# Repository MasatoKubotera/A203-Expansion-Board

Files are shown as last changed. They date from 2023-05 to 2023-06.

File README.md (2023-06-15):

<html lang="en">

<head>
    <meta charset="uft-8">
    <meta name="author" content="Masato Kubotera">
    <meta name="description" content="">
</head>

<body>
    <p><strong>This product is currently under development!</strong></p>
    <h1>A203 V2 Expansion Board</h1>
        <p>
            This product is a board that expands the functions of the A203 (Version 2) carrier board manufactured by Seeed Stuido, developed for the SUSTAINA-OP<sup>TM</sup>. Several modules developed for SUSTAINA-OP<sup>TM</sup> can be attached/connected to this board and used by connecting to the Multifunctional Port and USB Port on the carrier board. In addition, the USB 2.0 High Speed(480MHz) 3-Port Hub is installed for further expandability.
        </p>
    <h2>Features Rev. 1</h2>
        <p>
            <table>
                <tr>
                    <th>Top Surface of PCB</th>
                    <th>Bottom Surface of PCB</th>
                    <th>Assembled Electronic Components</th>
                </tr>
                <tr>
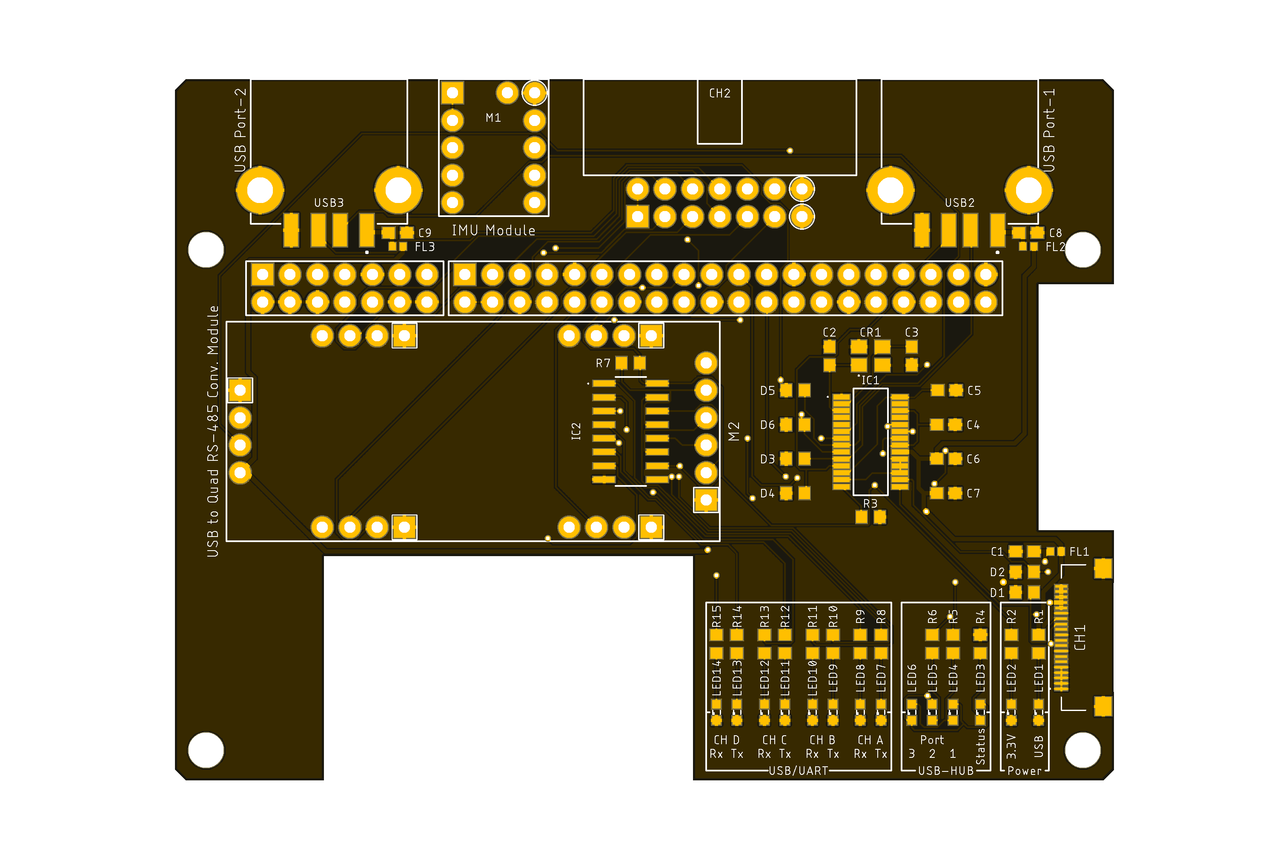
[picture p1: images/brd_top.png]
                    <td></td>
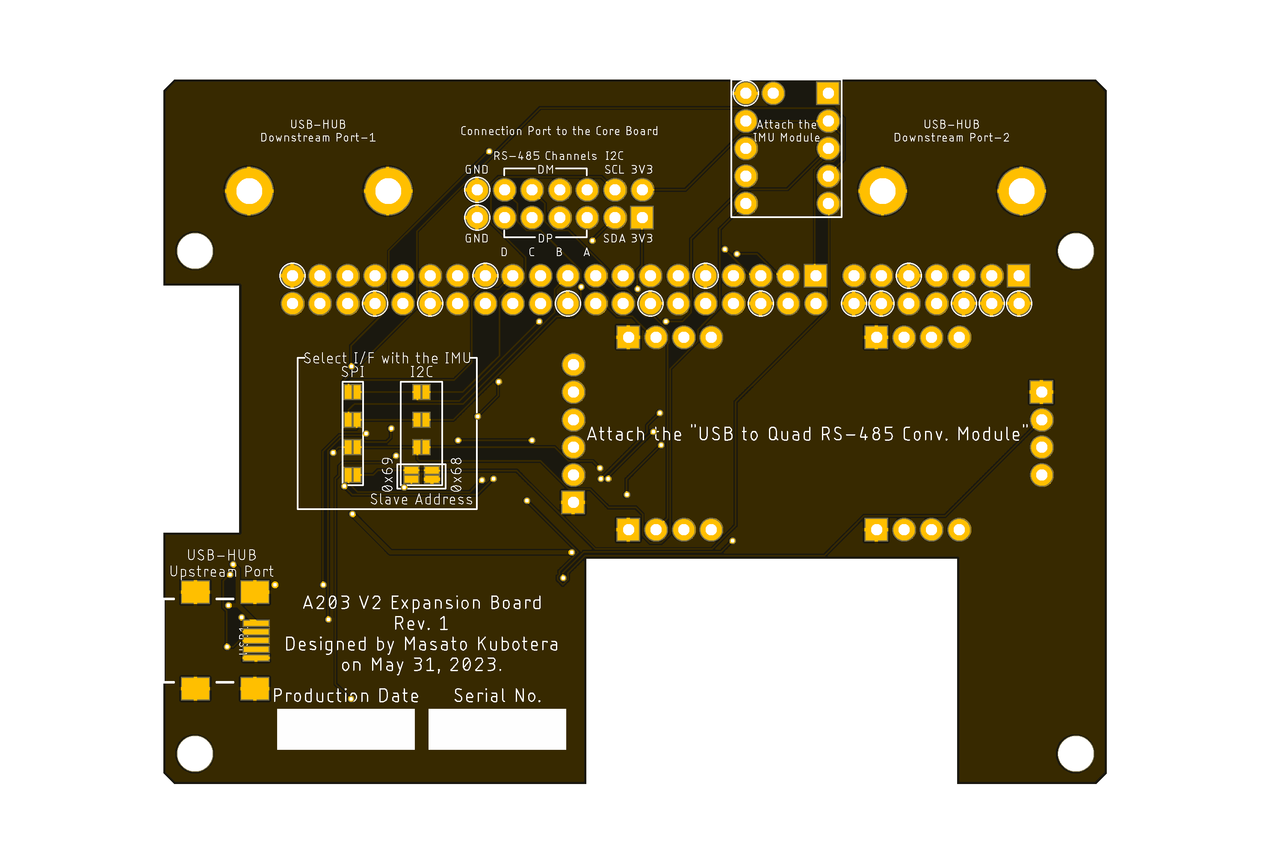
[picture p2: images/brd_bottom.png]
                    <td></td>
                    <td></td>
                </tr>
            </table>
        </p>
    <h3>PCB</h3>
        <p>
            <ul>
                <li>81.20mm x 46.40mm PCB layout</li>
                The shape of the connector does not interfere with the connectors on the A203 V2.
                <li>Two types of USB-HUB Upstream Ports</li>
                    <ul>
                        <li>0.5mm pitch 20P ZIF Connector</li>
                        Compliant with W11: 20PIN(USB 3.0 ZIF) on the A203 V2.
                        <li>USB Mini-B Connector (Optional)</li>
                    </ul>
                <li>2 x USB 2.0 Type-A USB-HUB Downstream Ports</li>
                <li>1 x <a href="https://github.com/SUSTAINA-OP/ICM-42688-P-Module">SUSTAINA-OP/ICM-42688-P-Module</a> Attachment Port</li>
                The I/F with A203V2 can be selected from the following using the shortlands on the product.
                <ul>
                    <li>SPI </li>
                    <li>I2C: Selectable slave address 0x68/0x69</li>
                </ul>
                <li>1 x <a href="https://github.com/SUSTAINA-OP/USB-to-Quad-RS-485-Conv-Module">SUSTAINA-OP/USB-to-Quad-RS-485-Conv-Module</a> Attachment Port</li>
                <li>14 x LED Indicators</li>
                <li>
                    1 x Port for Connection to <a href="https://github.com/SUSTAINA-OP/SUSTAINA-Core-Board">SUSTAINA-OP/SUSTAINA-Core-Board</a>
                    <ul>
                        <li>2 x 7 Pin Flat Cable Connector (MIL Standard Connector)
                            <ul>
                                <li><strong>2 x 3V3</strong>: 3.3 V Power Supply</li>
                                <li><strong>SCL</strong>: I2C Serial Clock</li>
                                <li><strong>SDA</strong>: I2C Serial Data</li>
                                <li><strong>A-DP</strong>: RS-485 Data Signal Plus of CH-A</li>
                                <li><strong>A-DM</strong>: RS-485 Data Signal Minus of CH-A</li>
                                <li><strong>B-DP</strong>: RS-485 Data Signal Plus of CH-B</li>
                                <li><strong>B-DM</strong>: RS-485 Data Signal Minus of CH-B</li>
                                <li><strong>C-DP</strong>: RS-485 Data Signal Plus of CH-C</li>
                                <li><strong>C-DM</strong>: RS-485 Data Signal Minus of CH-C</li>
                                <li><strong>D-DP</strong>: RS-485 Data Signal Plus of CH-D</li>
                                <li><strong>D-DM</strong>: RS-485 Data Signal Minus of CH-D</li>
                                <li><strong>2 x GND</strong>: Common Ground</li>
                            </ul>
                        </li>
                    </ul>
                </li>
            </ul>
        </p>
    <h2>Development Environments</h2>
    <p>
        This product is designed with the following software.
            <ul>
                <li><a href="https://www.autodesk.com/products/eagle/overview">Autodesk Eagle 9.6.2</a></li>
            </ul>
    </p>
    <h2>Repository Contents</h2>
        <p>
            <dl>
                <dt><a href="/images">\images</a></dt>
                <dd>PCB preview images and capture of design screen</dd>
                <dt><a href="/libraries">\libraries</a></dt>
                <dd>Libraries used in Autodesk Eagle design</dd>
                <dt><a href="/pcb_order">\pcb_order</a> </dt>
                <dd>Gerber data and documentation for ordering PCB</dd>
                <dt><a href="/schematic.pdf">schematic.pdf</a></dt>
                <dd>Circuit diagram of this product</dd>
                <dt>*.brd</dt>
                <dd>Board wiring design file by Autodesk Eagle</dd>
                <dt>*.sch</dt>
                <dd>Circuit diagram design file by Autodesk Eagle</dd>
                <dt><a href="/.gitignore">.gitignore</a></dt>
                <dd>A file that tells Git not to track a particular file</dd>            <dt><a href="/LICENSE">LICENSE</a></dt>
                <dd>License to use this product</dd>
            </dl>
        </p>
    <h2>Documentation</h2>
        <p>
            The following documents are available for this product.
            <ul>
                <li><a href="/pcb_order/README.md">\pcb_order\README.md</a>: Information for ordering the PCB or PCBA</li>
            </ul>
        </p>
    <h2>References</h2>
        
    <h2>Contact</h2>
        <p>
            If you have any questions, please contact the designer of this product, Masato Kubodera, by <a href="mailto:masato.kubotera@sustaina-op.com">e-mail</a>.<br>
            E-mail: <a href="mailto:masato.kubotera@sustaina-op.com">masato.kubotera@sustaina-op.com</a>
        </p>
    <h2>License Information</h2>
        <p>
            This product is open source. Please review the <a href="/LICENSE">LICENSE</a> for license information.<br>
            <br>
            This product by Masato Kubotera is licensed under a <a href="http://creativecommons.org/licenses/by-nc-sa/4.0/">Creative Commons Attribution-NonCommercial-ShareAlike 4.0 International License</a>.
        </p>
</body>
</html>

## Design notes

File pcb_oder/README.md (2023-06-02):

<html lang="en">

<head>
	<meta charset="uft-8">
	<meta name="author" content="Masato Kubotera">
    <meta name="description" content="">
</head>

<body>
	<h1>PCB / PCBA Order</h1>
        <p>
            PCB/PCBA ordering were outsourced to <a href="https://jlcpcb.com/">JLCPCB</a>.<br>
            The following files were used to generate files for PCB/PCBA orders.
            <ul>
                <li>Eagle Design File:
                    <a href="https://github.com/JLCPCB/jlcpcb-eagle/blob/master/design%20rules/jlcpcb-2layers.dru">jlcpcb-2layers.dru</a>
                </li>
                <li>Eagle CAM File:
                    <a href="https://github.com/JLCPCB/jlcpcb-eagle/blob/master/cam/jlcpcb_2_layer_v9.cam">jlcpcb_2_layer_v9.cam</a>
                </li>
                <li>BOM/CPL Exporter ULPs:
                    <a href="https://github.com/JLCPCB/jlcpcb-eagle/blob/master/ulps/jlcpcb_smta_exporter.ulp">jlcpcb_smta_exporter.ulp</a>
                </li>
            </ul>
            These are distributed in <a href="https://github.com/JLCPCB/jlcpcb-eagle">github.com/JLCPCB/jlcpcb-eagle</a>.<br>
        </p>
    <h2>PCB Order Specifications</h2>
        <p>           
            <table>
                <tr>
                    <th>PCB Top Image</th>
                    <th>PCB Bottom Image</th>
                </tr>
                <tr>
                    <td></td>
                    <td></td>
                </tr>
            </table>
            The following  files used to order the PCB and their specifications. 
            <ul>
                <li>Gerber data: <a href="Gerber_date.zip">Gerber_date.zip</a></li>
            </ul>
            <details close>
                <summary>Click for more specifications</summary>
                <ul>                
                    <li>Base Material: FR-4</li>
                    <li>Layers: 2</li>
                    <li>Dimension: 87 mm* 65 mm</li>
                    <li>Product Type: Industrial/Consumer electronics</li>
                    <li>Different Design: 1</li>
                    <li>Delivery Format: Single PCB</li>
                    <li>PCB Thickness: 1.6</li>
                    <li>Impedance Control: no</li>
                    <li>PCB Color: Black</li>
                    <li>Silkscreen: White</li>
                    <li>Surface Finish: HASL(with lead)</li>
                    <li>Outer Copper Weight: 1 oz</li>
                    <li>Via Covering: Tented</li>
                    <li>Board Outline Tolerance: ±0.2mm(Regular)</li>
                    <li>Confirm Production file: No</li>                
                    <li>Remove Order Number: Yes</li>
                    <li>Deburring/Edge rounding: No</li>
                    <li>Flying Probe Test: Fully Test</li>
                    <li>Gold Fingers: No</li>
                    <li>Castellated Holes: No</li>
                    <li>4-Wire Kelvin Test: No</li>
                    <li>Paper between PCBs: No</li>
                    <li>Appearance Quality: IPC Class 2 Standard</li>
                    <li>Silkscreen Technology: Ink-jet/Screen Printing</li>
                    <li>Package Box: With JLCPCB logo</li>
                </ul>
            </details>
        </p>
    <h2>PCBA Order Specifications</h2>
        <p>
            <table>
                <tr><th>PCBA Image</th></tr>
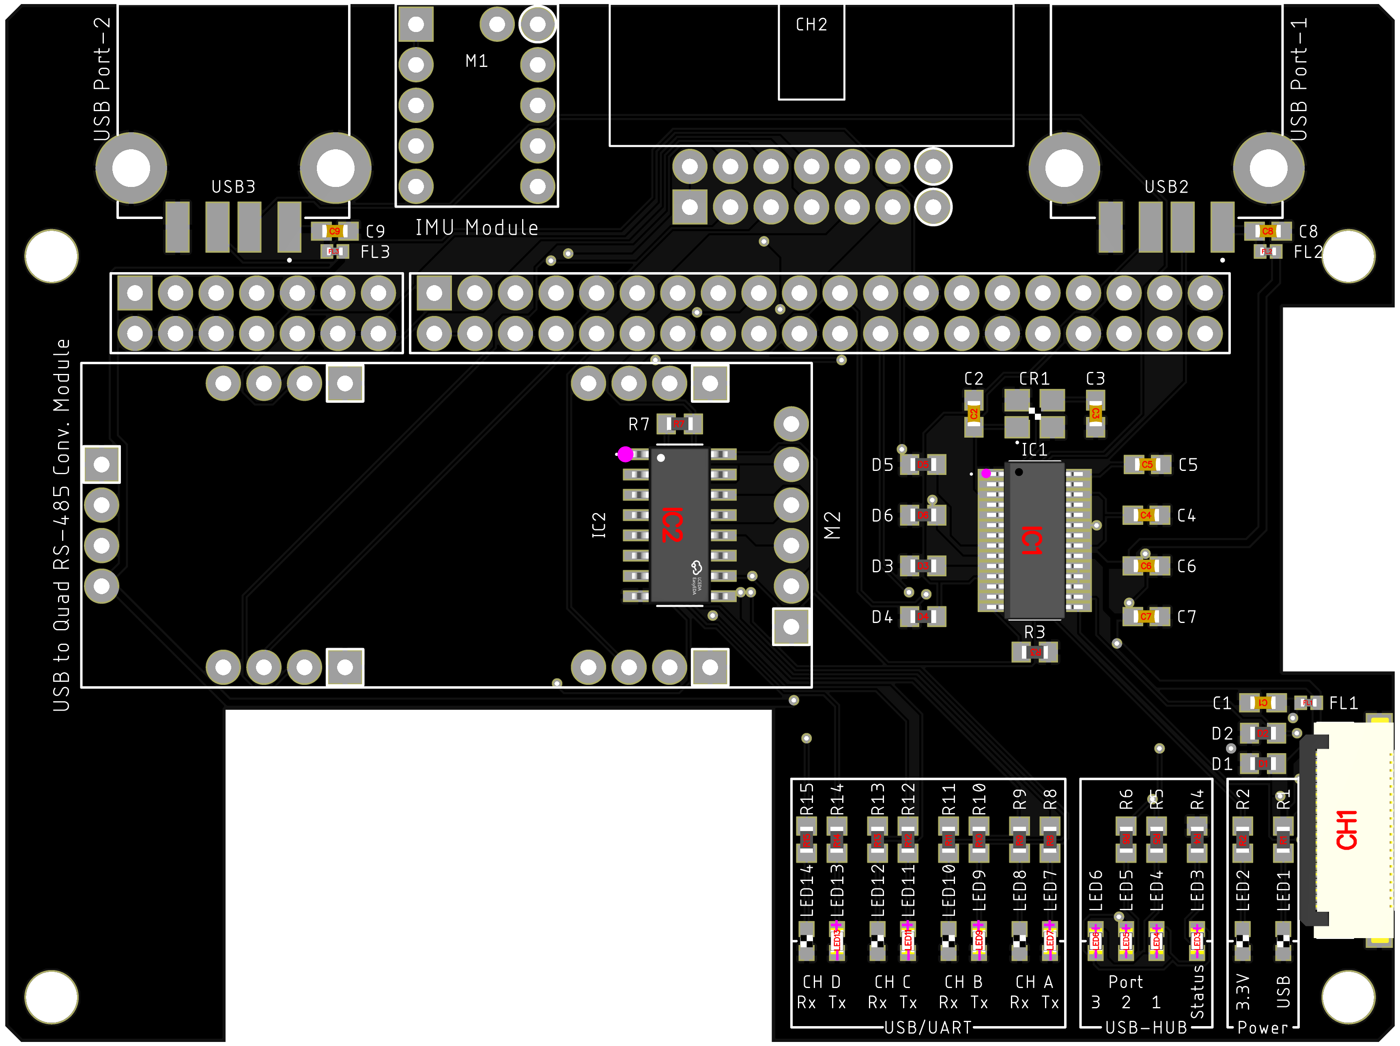
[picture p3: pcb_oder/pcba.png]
                <tr><td></td></tr>
            </table>
            The following files used to order the PCBA and their specifications.
            <ul>
                <li>BOM File: <a href="A203-V2-Expansion-Board_top_bom.csv">A203-V2-Expansion-Board_top_bom.csv</a></li>
                <li>CPL File: <a href="A203-V2-Expansion-Board_top_cpl.csv">A203-V2-Expansion-Board_top_cpl.csv</a></li>
            </ul>
            The following components were installed by PCBA.
            <table>
                <tr>
                    <th>Part Image</th>
                    <th>Top Designator</th>
                    <th>MFR.Part #</th>
                    <th>JLCPCB Part #</th>
                    <th>Manufacturer</th>
                    <th>Part Detail</th>
                </tr>
                <tr>
                    <td></td>
                    <td>C1, C7, C8, C9</td>
                    <td>GCM188R71H103KA37D</td>
                    <td><a href="https://jlcpcb.com/partdetail/MurataElectronics-GCM188R71H103KA37D/C85863">C85863</a></td>
                    <td>Murata Electronics</td>
                    <td>Multilayer Ceramic Capacitor SMD 10nF 50V ±10% X7R 0603</td>
                </tr>
                <tr>
                    <td></td>
                    <td>C2, C3</td>
                    <td>C1608C0G1H220JT000N</td>
                    <td><a href="https://jlcpcb.com/partdetail/Tdk-C1608C0G1H220JT000N/C183114">C183114</a></td>
                    <td>TDK</td>
                    <td>Multilayer Ceramic Capacitor SMD 22pF 50V ±5% C0G 0603</td>
                </tr>
                <tr>
                    <td></td>
                    <td>C4, C5, C6</td>
                    <td>GRM188R61C106KAALD</td>
                    <td><a href="https://jlcpcb.com/partdetail/MurataElectronics-GRM188R61C106KAALD/C86275">C86275</a></td>
                    <td>Murata Electronics</td>
                    <td>Multilayer Ceramic Capacitor SMD 10uF 16V ±10% X5R 0603</td>
                </tr>
                <tr>
                    <td></td>
                    <td>CR1</td>
                    <td>7V12006001</td>
                    <td><a href="https://jlcpcb.com/partdetail/TxcCorp-7V12006001/C5203634">C5203634</a></td>
                    <td>TXC Corp</td>
                    <td>Crystal 12Hz ±30ppm 12pF SMD 3225-4P</td>
                </tr>
                <tr>
                    <td></td>
                    <td>CH1</td>
                    <td>XF2M-2015-1A</td>
                    <td><a href="https://jlcpcb.com/partdetail/OmronElectronics-XF2M_20151A/C57541">C57541</a></td>
                    <td>Omron Electronics</td>
                    <td>FFC/FPC Connector SMD　20-pin 0.5mm Pitch Double-sided</td>
                </tr>
                <tr>
                    <td></td>
                    <td>D1, D2, D3, D4, D5, D6</td>
                    <td>PGB1010603MR</td>
                    <td><a href="https://jlcpcb.com/partdetail/Littelfuse-PGB1010603MR/C142698">C142698</a></td>
                    <td>Littelfuse</td>
                    <td>ESD Suppressor SMD 24V 0.06pF 0603</td>
                </tr>
                <tr>
                    <td></td>
                    <td>FL1,FL2,FL3</td>
                    <td>BLM15AX601SN1D</td>
                    <td><a href="https://jlcpcb.com/partdetail/MurataElectronics-BLM15AX601SN1D/C76886">C76886</a></td>
                    <td>Murata Electronics</td>
                    <td>Ferrite Bead SMD 600Ω ±25% 500mA 0402</td>
                </tr>
                <tr>
                    <td></td>
                    <td>IC1</td>
                    <td>FE1.1S</td>
                    <td><a href="https://jlcpcb.com/partdetail/TerminusTech-FE1_1SBSOP28BCN/C9359">C9359</a></td>
                    <td>Terminus Tech</td>
                    <td>USB Interface IC USB 2.0 Hi-Speed 4-port Hub Controller SSOP-28</td>
                </tr>
                <tr>
                    <td></td>
                    <td>IC2</td>
                    <td>SN74HC595DR</td>
                    <td><a href="https://jlcpcb.com/partdetail/TexasInstruments-SN74HC595DR/C10092">C10092</a></td>
                    <td>Texas Instruments</td>
                    <td>Shift Register 8-bit 6V SOIC-16</td>
                </tr>
                <tr>
                    <td></td>
                    <td>LED1, LED2, LED8, LED10, LED12, LED14</td>
                    <td>SML-D12M1WT86</td>
                    <td><a href="https://jlcpcb.com/partdetail/RohmSemicon-SMLD12M1WT86/C2922668">C2922668</a></td>
                    <td>ROHM Semicon</td>
                    <td>Standard LED SMD GREEN 2.2V 20mA 572nm 0603
                </tr>
                <tr>
                    <td></td>
                    <td>LED3, LED4, LED5, LED6</td>
                    <td>SML-D12Y1WT86</td>
                    <td><a href="https://jlcpcb.com/partdetail/RohmSemicon-SMLD12Y1WT86/C253534">C253534</a></td>
                    <td>ROHM Semicon</td>
                    <td>Standard LED SMD YELLOW 2.2V 20mA 590nm 0603</td>
                </tr>             
                <tr>
                    <td></td>
                    <td>LED7, LED9, LED11, LED13</td>
                    <td>SML-D12V1WT86</td>
                    <td><a href="https://jlcpcb.com/partdetail/RohmSemicon-SMLD12V1WT86/C253533">C253533</a></td>
                    <td>ROHM Semicon</td>
                    <td>Standard LED SMD RED 2.2V 20mA 630nm 0603</td>
                </tr>
                <tr>
                    <td></td>
                    <td>R1, R2, R4, R5, R6, R8, R9, R10, R11, R12, R13, R14, R15</td>
                    <td>RC0603FR-071KL</td>
                    <td><a href="https://jlcpcb.com/partdetail/Yageo-RC0603FR071KL/C22548">C22548</a></td>
                    <td>YAGEO</td>
                    <td>Thick Film Resistor SMD 1kΩ 1/10W ±1% 0603</td>
                </tr>
                <tr>
                    <td></td>
                    <td>R3</td>
                    <td>RC0603FR-072K7L</td>
                    <td><a href="https://jlcpcb.com/partdetail/Yageo-RC0603FR072K7L/C114612">C114612</a></td>
                    <td>YAGEO</td>
                    <td>Thick Film Resistor SMD 2.7kΩ 1/10W ±1% 0603</td>
                </tr>
                <tr>
                    <td></td>
                    <td>R7</td>
                    <td>RC0603FR-0710KL</td>
                    <td><a href="https://jlcpcb.com/partdetail/Yageo-RC0603FR0710KL/C98220">C98220</a></td>
                    <td>YAGEO</td>
                    <td>Thick Film Resistor SMD 10kΩ 1/10W ±1% 0603</td>
                </tr>
            </table>
            The following components are not handled by JLCPCB and could not be attached by PCBA.
            <table>
                <tr>
                    <th>Top Designator</th>
                    <th>MFR.Part #</th>
                    <th>Distributor / Part #</th>
                    <th>Manufacturer</th>
                    <th>Part Detail</th>
                </tr>
                <tr>
                    <td>CH2</td>
                    <td>HIF3FC-14PA-2.54DS(71)</td>
                    <td><a href="https://www.mouser.jp/ProductDetail/798-HIF3FC14PA254DS1">Mouser / 798-HIF3FC14PA254DS1</a></td>
                    <td><a href="https://www.hirose.com/en/product/p/CL0616-0062-2-71">Hirose Connector</a></td>
                    <td>Low Profile Connector 2.54mm-pitch 14-pin</td>
                </tr>
                <tr>
                    <td>USB2, USB3</td>
                    <td>USB1046-GF-0190-L-B-A</td>
                    <td><a href="https://www.mouser.jp/ProductDetail/640-USB1046GF0190LBA">Mouser / 640-USB1046GF0190LBA</a></td>
                    <td>GCT</td>
                    <td>USB Connectors SMD USB2.0 Type-A Top Mount</td>
                </tr>            
            </table>
            The following components were not attached due to being optional components to be attached to the bottom surface.
            <table>
                <tr>
                    <th>Top Designator</th>
                    <th>MFR.Part #</th>
                    <th>Distributor / Part #</th>
                    <th>Manufacturer</th>
                    <th>Part Detail</th>
                </tr>
                <tr>
                    <td>USB1</td>
                    <td>MUSB-5B-NE-S175</td>
                    <td><a href="https://akizukidenshi.com/catalog/g/gC-05843/">Akizuki / C-05843</a></td>
                    <td>Useconn Electronics Ltd.</td>
                    <td>USB Connectors SMD USB2.0 Mini-B Top Mount</td>
                </tr>           
            </table>
            These selected parts are listed in <a href="bom.xls">bom.xls</a>.<br>
            <details close>
                <summary>Click for more specifications</summary>
                <ul>                
                    <li>PCBA Type: Economic</li>
                    <li>Assembly Side: Top Side</li>
                    <li>Tooling holes: Added by JLCPCB</li>
                    <li>Confirm Parts Placement: No</li>
                </ul>
            </details>
        </p>
</body>

</html>

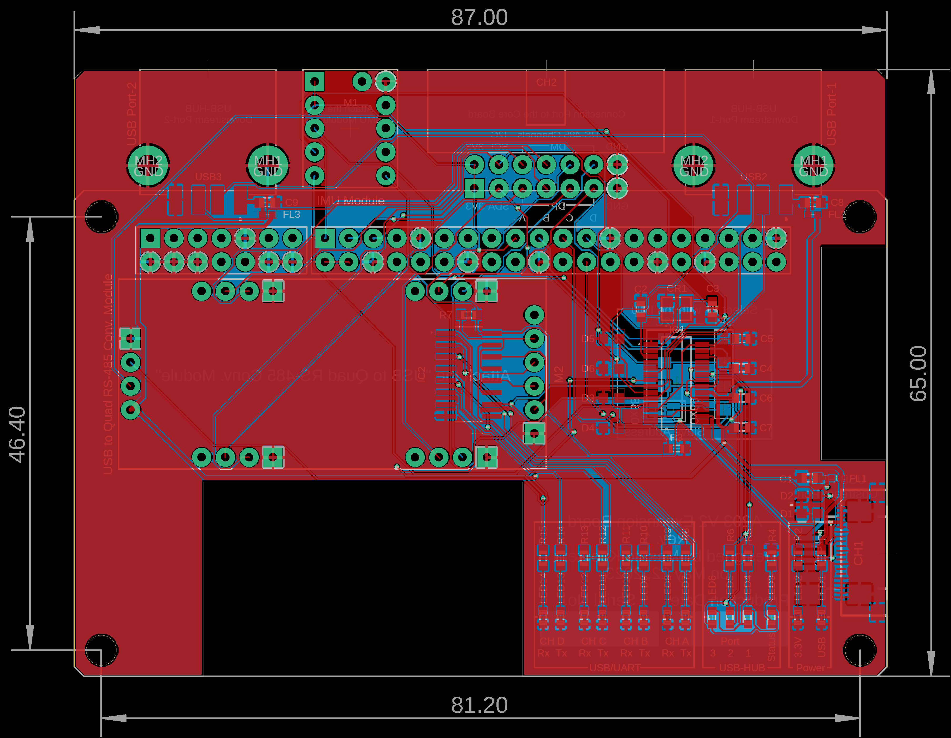
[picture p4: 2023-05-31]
images/brd.png

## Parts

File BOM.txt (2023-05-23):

Qty Value                                 Device                                Package                             Parts                                                    Description                
4   0.01u                                 C-USC0603                             C0603                               C1, C7, C8, C9                                           CAPACITOR, American symbol 
1   10k                                   R-US_R0603                            R0603                               R7                                                       RESISTOR, American symbol  
3   10u                                   C-USC0603                             C0603                               C4, C5, C6                                               CAPACITOR, American symbol 
13  1k                                    R-US_R0603                            R0603                               R1, R2, R4, R5, R6, R8, R9, R10, R11, R12, R13, R14, R15 RESISTOR, American symbol  
1   2.7k                                  R-US_R0603                            R0603                               R3                                                       RESISTOR, American symbol  
2   22p                                   C-USC0603                             C0603                               C2, C3                                                   CAPACITOR, American symbol 
1   7V12006001                            7V12006001                            7V12006001                          CR1                                                                                 
3   BLM15AX601SN1D                        BLM15AX601SN1D                        BLM15AX601SN1D                      FL1, FL2, FL3                                                                       
1   FE1.1S                                FE1.1S                                FE1.1S                              IC1                                                                                 
6   Green                                 LEDSML0603                            SML0603                             LED1, LED2, LED8, LED10, LED12, LED14                    LED                        
1   HIF3FC-14PA-2.54DS(71)                HIF3FC-14PA-2.54DS(71)                HIF3FC-14PA-2.54DS(71)              CH2                                                                                 
1   ICM-42688-P-MODULE-PINHEADER          ICM-42688-P-MODULE-PINHEADER          ICM-42688-P-MODULE-PINHEADER        M1                                                                                  
1   MINI_USB_B_SMD                        MINI_USB_B_SMD                        MINI_USB_B_SMD                      USB1                                                                                
6   PGB1010603MR                          PGB1010603MR                          0603                                D1, D2, D3, D4, D5, D6                                                              
4   Red                                   LEDSML0603                            SML0603                             LED7, LED9, LED11, LED13                                 LED                        
1   SEEED_A207_V2                         SEEED_A207_V2                         SEEED_A203_V2                       B1                                                                                  
9   SHORTLAND                             SHORTLAND                             SHORTLAND                           JP1, JP2, JP3, JP4, JP5, JP6, JP7, JP8, JP9                                         
1   SN74HC595DR                           SN74HC595DR                           SOIC-16                             IC2                                                                                 
1   USB-TO-QUAD-RS-485-CONV-MODULET-PLACE USB-TO-QUAD-RS-485-CONV-MODULET-PLACE USB-TO-QUAD-RS-485-CONV-MODULE-SILK M2                                                                                  
2   USB_A_X1_SMD                          USB_A_X1_SMD                          USB_A_X1_SMD                        USB2, USB3                                                                          
1   XF2M-2015-1A                          XF2M-2015-1A                          XF2M-2015-1A                        CH1                                                                                 
4   Yellow                                LEDSML0603                            SML0603                             LED3, LED4, LED5, LED6                                   LED

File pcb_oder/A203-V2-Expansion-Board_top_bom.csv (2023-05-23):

Comment | Designator | Footprint | LCSC Part #
0.01u | C1 C7 C8 C9 | C0603 | C85863
22p | C2 C3 | C0603 | C183114
10u | C4 C5 C6 | C0603 | C86275
XF2M-2015-1A | CH1 | XF2M-2015-1A | C57541
7V12006001 | CR1 | 7V12006001 | C5203634
PGB1010603MR | D1 D2 D3 D4 D5 D6 | 603 | C142698
BLM15AX601SN1D | FL1 FL2 FL3 | BLM15AX601SN1D | C76886
FE1.1S | IC1 | FE1.1S | C9359
SN74HC595DR | IC2 | SOIC-16 | C10092
Green | LED1 LED2 LED8 LED10 LED12 LED14 | SML0603 | C2922668
Yellow | LED3 LED4 LED5 LED6 | SML0603 | C253534
Red | LED7 LED9 LED11 LED13 | SML0603 | C253533
1k | R1 R2 R4 R5 R6 R8 R9 R10 R11 R12 R13 R14 R15 | R0603 | C22548
2.7k | R3 | R0603 | C114612
10k | R7 | R0603 | C98220
USB_A_X1_SMD | USB2 USB3 | USB_A_X1_SMD

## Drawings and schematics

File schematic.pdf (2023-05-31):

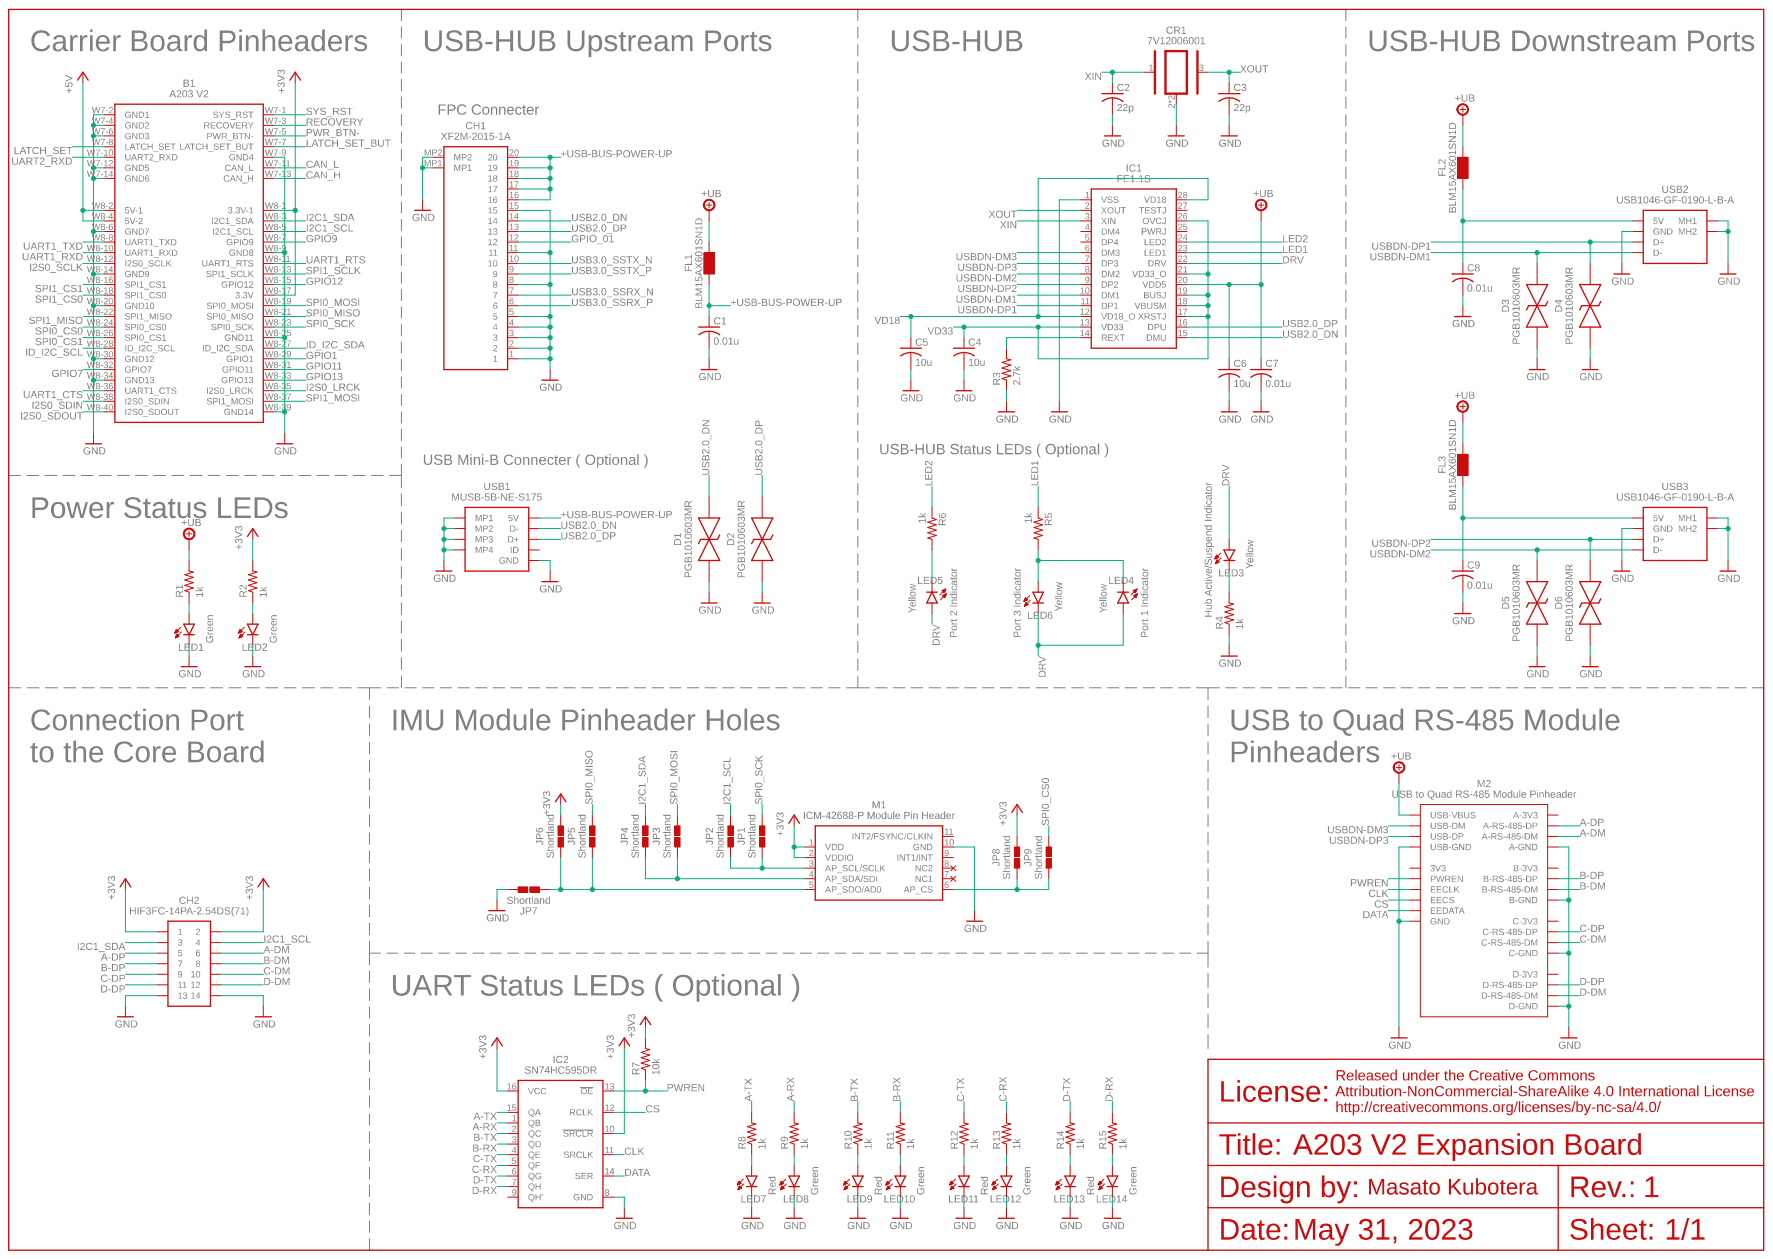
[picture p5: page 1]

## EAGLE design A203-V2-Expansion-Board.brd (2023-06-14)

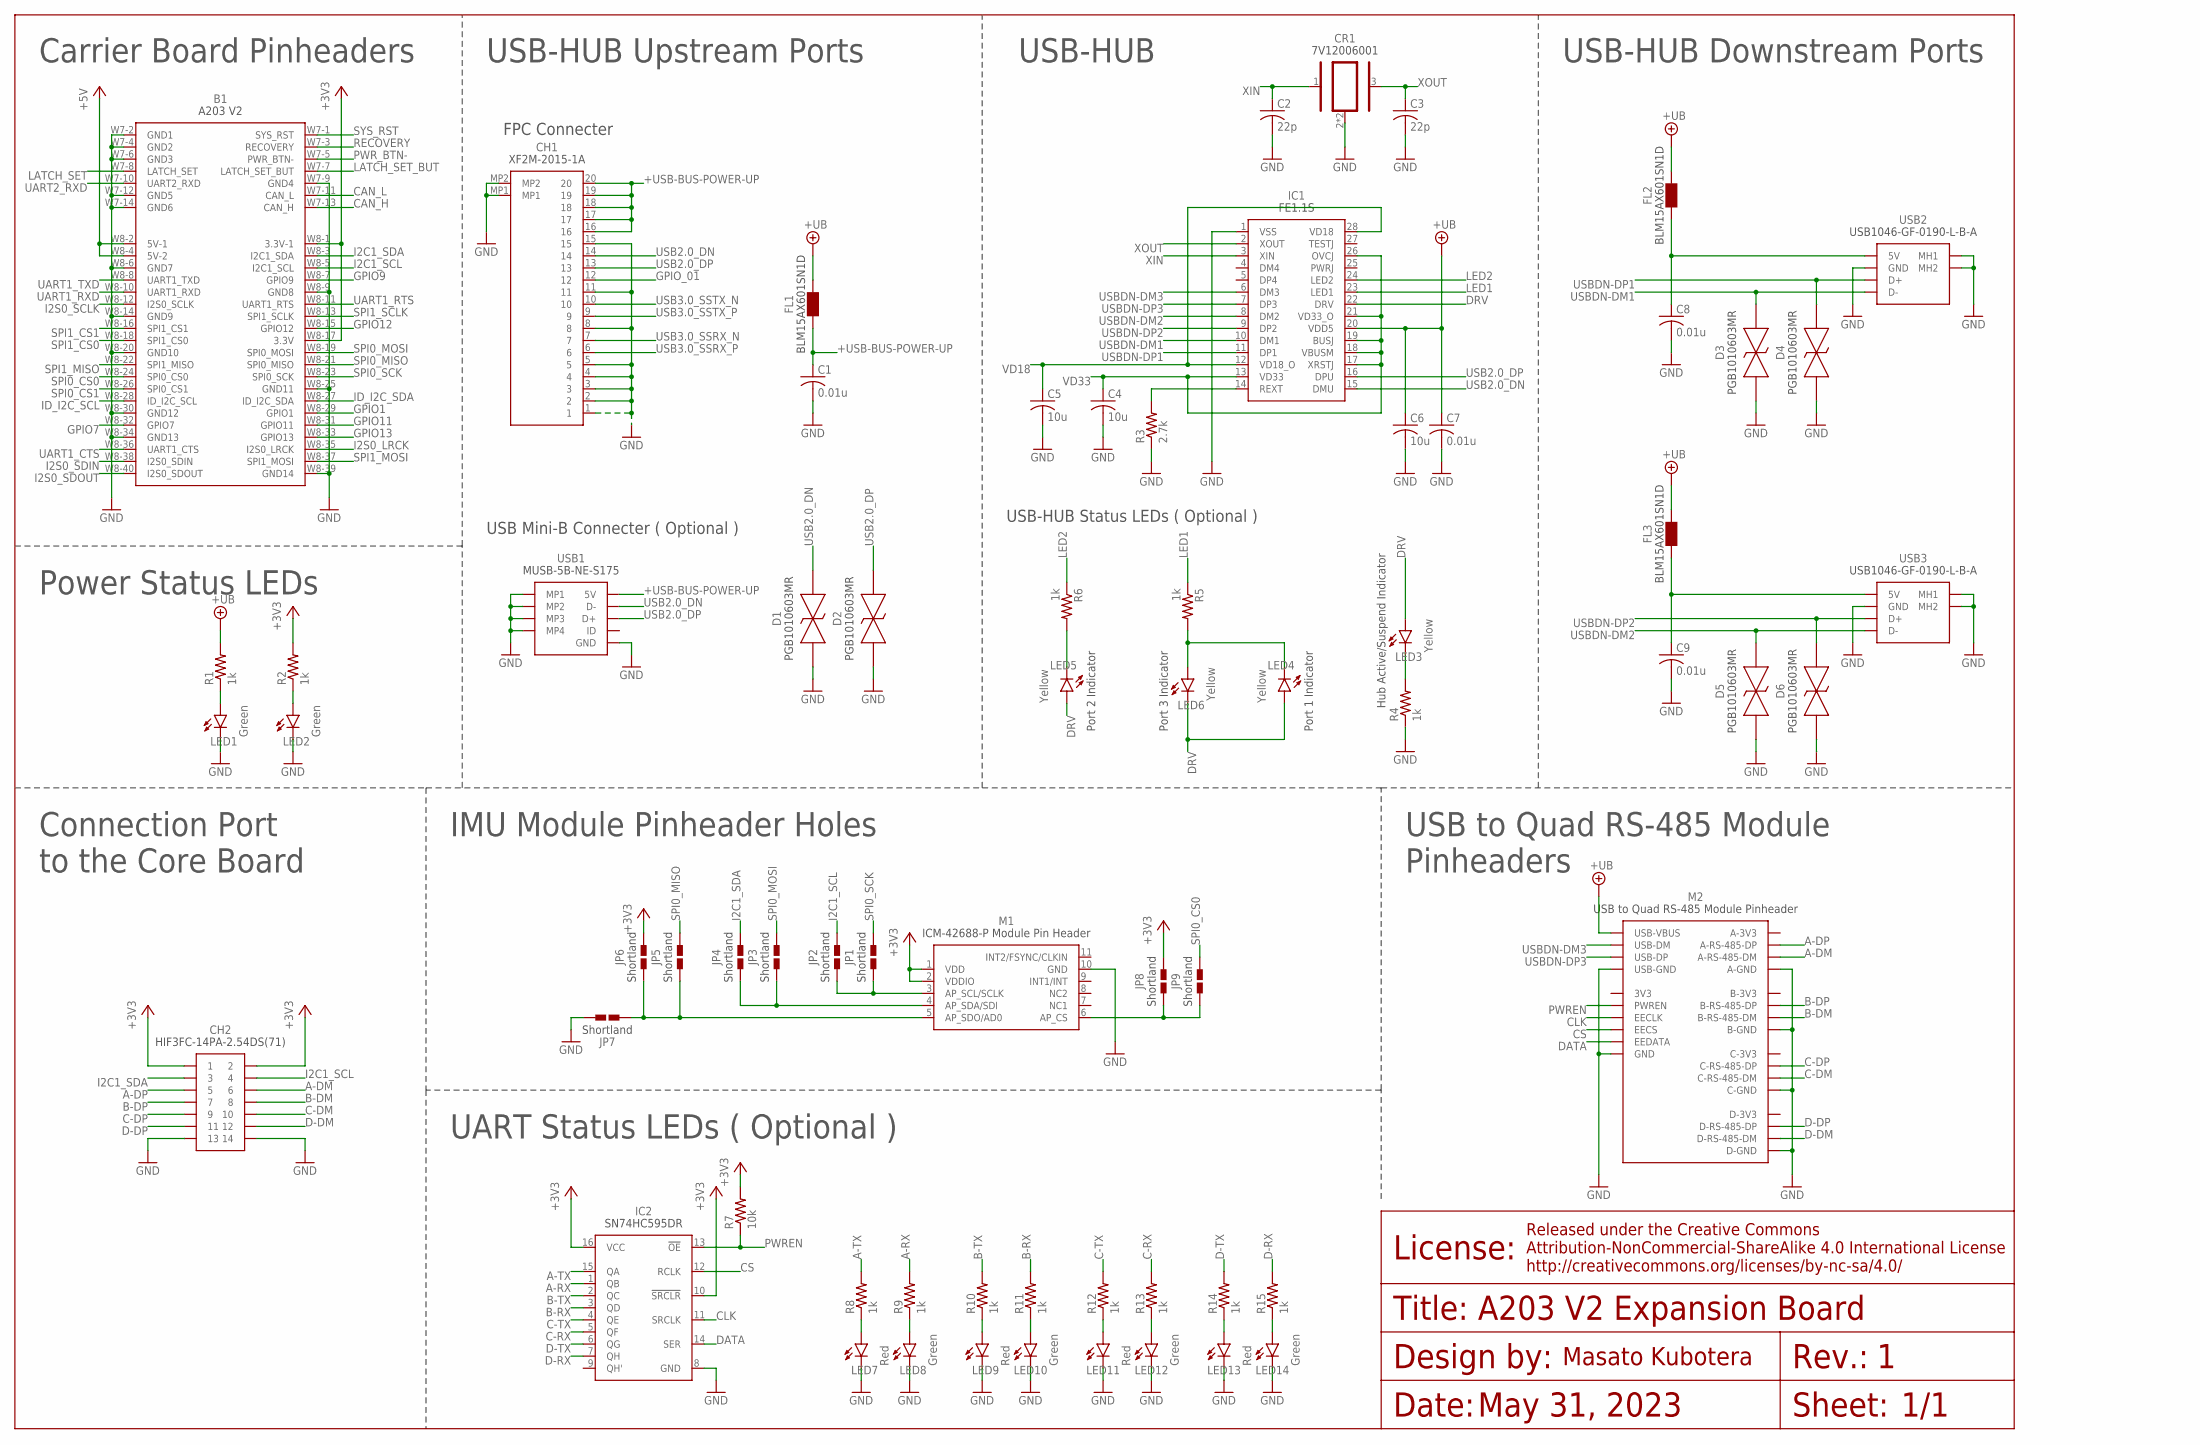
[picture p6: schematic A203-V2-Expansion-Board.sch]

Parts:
B1: SEEED_A207_V2; SEEED_A203_V2
C1, C7, C8, C9: 0.01u; C0603
C2, C3: 22p; C0603
C4, C5, C6: 10u; C0603
CH1: XF2M-2015-1A
CH2: HIF3FC-14PA-2.54DS(71)
CR1: 7V12006001
D1, D2, D3, D4, D5, D6: PGB1010603MR; 0603
FL1, FL2, FL3: BLM15AX601SN1D
IC1: FE1.1S
IC2: SN74HC595DR; SOIC-16
JP1, JP2, JP3, JP4, JP5, JP6, JP7, JP8, JP9: SHORTLAND
LED1, LED2, LED8, LED10, LED12, LED14: Green; SML0603
LED3, LED4, LED5, LED6: Yellow; SML0603
LED7, LED9, LED11, LED13: Red; SML0603
M1: ICM-42688-P-MODULE-PINHEADER
M2: USB-TO-QUAD-RS-485-CONV-MODULET-PLACE; USB-TO-QUAD-RS-485-CONV-MODULE-SILK
R1, R2, R4, R5, R6, R8, R9, R10, R11, R12, R13, R14, R15: 1k; R0603
R3: 2.7k; R0603
R7: 10k; R0603
USB1: MINI_USB_B_SMD
USB2, USB3: USB_A_X1_SMD

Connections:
+3V3: B1.W8-1 (3.3V-1), B1.W8-17 (3.3V), CH2.1, CH2.2, IC2.10 (!SRCLR), IC2.16 (VCC), JP6.2, JP8.2, M1.1 (VDD), M1.2 (VDDIO), R2.2, R7.2
+5V: B1.W8-2 (5V-1), B1.W8-4 (5V-2)
+UB: C6.1, C7.1, FL1.2, FL2.2, FL3.2, IC1.20 (VDD5), M2.USB-VBUS, R1.2
+USB-BUS-POWER-UP: C1.1, CH1.16, CH1.17, CH1.18, CH1.19, CH1.20, FL1.1, USB1.1 (5V)
+USB-BUS-POWER_DN1: C8.1, FL2.1, USB2.1 (5V)
+USB-BUS-POWER_DN2: C9.1, FL3.1, USB3.1 (5V)
A-DM: CH2.6, M2.A-RS-485-DM
A-DP: CH2.5, M2.A-RS-485-DP
A-RX: IC2.1 (QB), R9.2
A-TX: IC2.15 (QA), R8.2
AP_CS: JP8.1, JP9.1, M1.6 (AP_CS)
AP_SCL/SCLK: JP1.1, JP2.1, M1.3 (AP_SCL/SCLK)
AP_SDA/SDI: JP3.1, JP4.1, M1.4 (AP_SDA/SDI)
AP_SDO/ADO: JP5.1, JP6.1, JP7.1, M1.5 (AP_SDO/AD0)
B-DM: CH2.8, M2.B-RS-485-DM
B-DP: CH2.7, M2.B-RS-485-DP
B-RX: IC2.3 (QD), R11.2
B-TX: IC2.2 (QC), R10.2
C-DM: CH2.10, M2.C-RS-485-DM
C-DP: CH2.9, M2.C-RS-485-DP
C-RX: IC2.5 (QF), R13.2
C-TX: IC2.4 (QE), R12.2
CAN_H: B1.W7-13 (CAN_H)
CAN_L: B1.W7-11 (CAN_L)
CLK: IC2.11 (SRCLK), M2.EECLK
CS: IC2.12 (RCLK), M2.EECS
D-DM: CH2.12, M2.D-RS-485-DM
D-DP: CH2.11, M2.D-RS-485-DP
D-RX: IC2.7 (QH), R15.2
D-TX: IC2.6 (QG), R14.2
DATA: IC2.14 (SER), M2.EEDATA
DRV: IC1.22 (DRV), LED3.A, LED4.A, LED5.A, LED6.C
GND: B1.W7-2 (GND1), B1.W7-4 (GND2), B1.W7-6 (GND3), B1.W7-9 (GND4), B1.W7-12 (GND5), B1.W7-14 (GND6), B1.W8-6 (GND7), B1.W8-9 (GND8), B1.W8-14 (GND9), B1.W8-20 (GND10), B1.W8-25 (GND11), B1.W8-30 (GND12), B1.W8-34 (GND13), B1.W8-39 (GND14), C1.2, C2.2, C3.2, C4.2, C5.2, C6.2, C7.2, C8.2, C9.2, CH1.1, CH1.2, CH1.3, CH1.4, CH1.5, CH1.8, CH1.11, CH1.15, CH1.MP1, CH1.MP2, CH2.13, CH2.14, CR1.2, CR1.4, D1.1, D2.1, D3.1, D4.1, D5.1, D6.1, IC1.1 (VSS), IC2.8 (GND), JP7.2, LED1.C, LED2.C, LED7.C, LED8.C, LED9.C, LED10.C, LED11.C, LED12.C, LED13.C, LED14.C, M1.10 (GND), M2.A-GND, M2.B-GND, M2.C-GND, M2.D-GND, M2.GND1 (GND), M2.USB-GND, R3.1, R4.1, USB1.5 (GND), USB1.MP1, USB1.MP2, USB1.MP3, USB1.MP4, USB2.4 (GND), USB2.MH1, USB2.MH2, USB3.4 (GND), USB3.MH1, USB3.MH2
GPIO1: B1.W8-29 (GPIO1)
GPIO7: B1.W8-32 (GPIO7)
GPIO9: B1.W8-7 (GPIO9)
GPIO11: B1.W8-31 (GPIO11)
GPIO12: B1.W8-15 (GPIO12)
GPIO13: B1.W8-33 (GPIO13)
GPIO_01: CH1.12
I2C1_SCL: B1.W8-5 (I2C1_SCL), CH2.4, JP2.2
I2C1_SDA: B1.W8-3 (I2C1_SDA), CH2.3, JP4.2
I2S0_LRCK: B1.W8-35 (I2S0_LRCK)
I2S0_SCLK: B1.W8-12 (I2S0_SCLK)
I2S0_SDIN: B1.W8-38 (I2S0_SDIN)
I2S0_SDOUT: B1.W8-40 (I2S0_SDOUT)
ID_I2C_SCL: B1.W8-28 (ID_I2C_SCL)
ID_I2C_SDA: B1.W8-27 (ID_I2C_SDA)
LATCH_SET: B1.W7-8 (LATCH_SET)
LATCH_SET_BUT: B1.W7-7 (LATCH_SET_BUT)
LED1: IC1.23 (LED1), R5.1
LED2: IC1.24 (LED2), R6.1
LED-3V3: LED2.A, R2.1
LED-A-RX: LED8.A, R9.1
LED-A-TX: LED7.A, R8.1
LED-B-RX: LED10.A, R11.1
LED-B-TX: LED9.A, R10.1
LED-C-RX: LED12.A, R13.1
LED-C-TX: LED11.A, R12.1
LED-D-RX: LED14.A, R15.1
LED-D-TX: LED13.A, R14.1
LED-FE1.1S-DRV: LED3.C, R4.2
LED-FE1.1S-INDIVATOR1: LED4.C, LED6.A, R5.2
LED-FE1.1S-INDIVATOR2: LED5.C, R6.2
LED-UB: LED1.A, R1.1
PWREN: IC2.13 (!OE), M2.PWREN, R7.1
PWR_BTN-: B1.W7-5 (PWR_BTN-)
RECOVERY: B1.W7-3 (RECOVERY)
REXT_FE1.1S: IC1.14 (REXT), R3.2
SPI0_CS0: B1.W8-24 (SPI0_CS0), JP9.2
SPI0_CS1: B1.W8-26 (SPI0_CS1)
SPI0_MISO: B1.W8-21 (SPI0_MISO), JP5.2
SPI0_MOSI: B1.W8-19 (SPI0_MOSI), JP3.2
SPI0_SCK: B1.W8-23 (SPI0_SCK), JP1.2
SPI1_CS0: B1.W8-18 (SPI1_CS0)
SPI1_CS1: B1.W8-16 (SPI1_CS1)
SPI1_MISO: B1.W8-22 (SPI1_MISO)
SPI1_MOSI: B1.W8-37 (SPI1_MOSI)
SPI1_SCLK: B1.W8-13 (SPI1_SCLK)
SYS_RST: B1.W7-1 (SYS_RST)
UART1_CTS: B1.W8-36 (UART1_CTS)
UART1_RTS: B1.W8-11 (UART1_RTS)
UART1_RXD: B1.W8-10 (UART1_RXD)
UART1_TXD: B1.W8-8 (UART1_TXD)
UART2_RXD: B1.W7-10 (UART2_RXD)
USB2.0_DN: CH1.14, D1.2, IC1.15 (DMU), USB1.2 (D-)
USB2.0_DP: CH1.13, D2.2, IC1.16 (DPU), USB1.3 (D+)
USB3.0_SSRX_N: CH1.7
USB3.0_SSRX_P: CH1.6
USB3.0_SSTX_N: CH1.10
USB3.0_SSTX_P: CH1.9
USBDN-DM1: D3.2, IC1.10 (DM1), USB2.2 (D-)
USBDN-DM2: D5.2, IC1.8 (DM2), USB3.2 (D-)
USBDN-DM3: IC1.6 (DM3), M2.USB-DM
USBDN-DP1: D4.2, IC1.11 (DP1), USB2.3 (D+)
USBDN-DP2: D6.2, IC1.9 (DP2), USB3.3 (D+)
USBDN-DP3: IC1.7 (DP3), M2.USB-DP
VD18: C5.1, IC1.12 (VD18_O), IC1.28 (VD18)
VD33: C4.1, IC1.13 (VD33), IC1.17 (XRSTJ), IC1.18 (VBUSM), IC1.19 (BUSJ), IC1.21 (VD33_O), IC1.26 (OVCJ)
XIN: C2.1, CR1.1, IC1.3 (XIN)
XOUT: C3.1, CR1.3, IC1.2 (XOUT)

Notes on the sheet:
Carrier Board Pinheaders
Power Status LEDs
UART Status LEDs ( Optional )
IMU Module Pinheader Holes
USB to Quad RS-485 Module Pinheaders
USB-HUB Upstream Ports
Connection Port to the Core Board
USB-HUB Downstream Ports
USB-HUB
1/1
May 31, 2023
A203 V2 Expansion Board
Hub Active/Suspend Indicator
Port 1 Indicator
Port 2 Indicator
Port 3 Indicator
USB Mini-B Connecter ( Optional )
FPC Connecter
USB-HUB Status LEDs ( Optional )

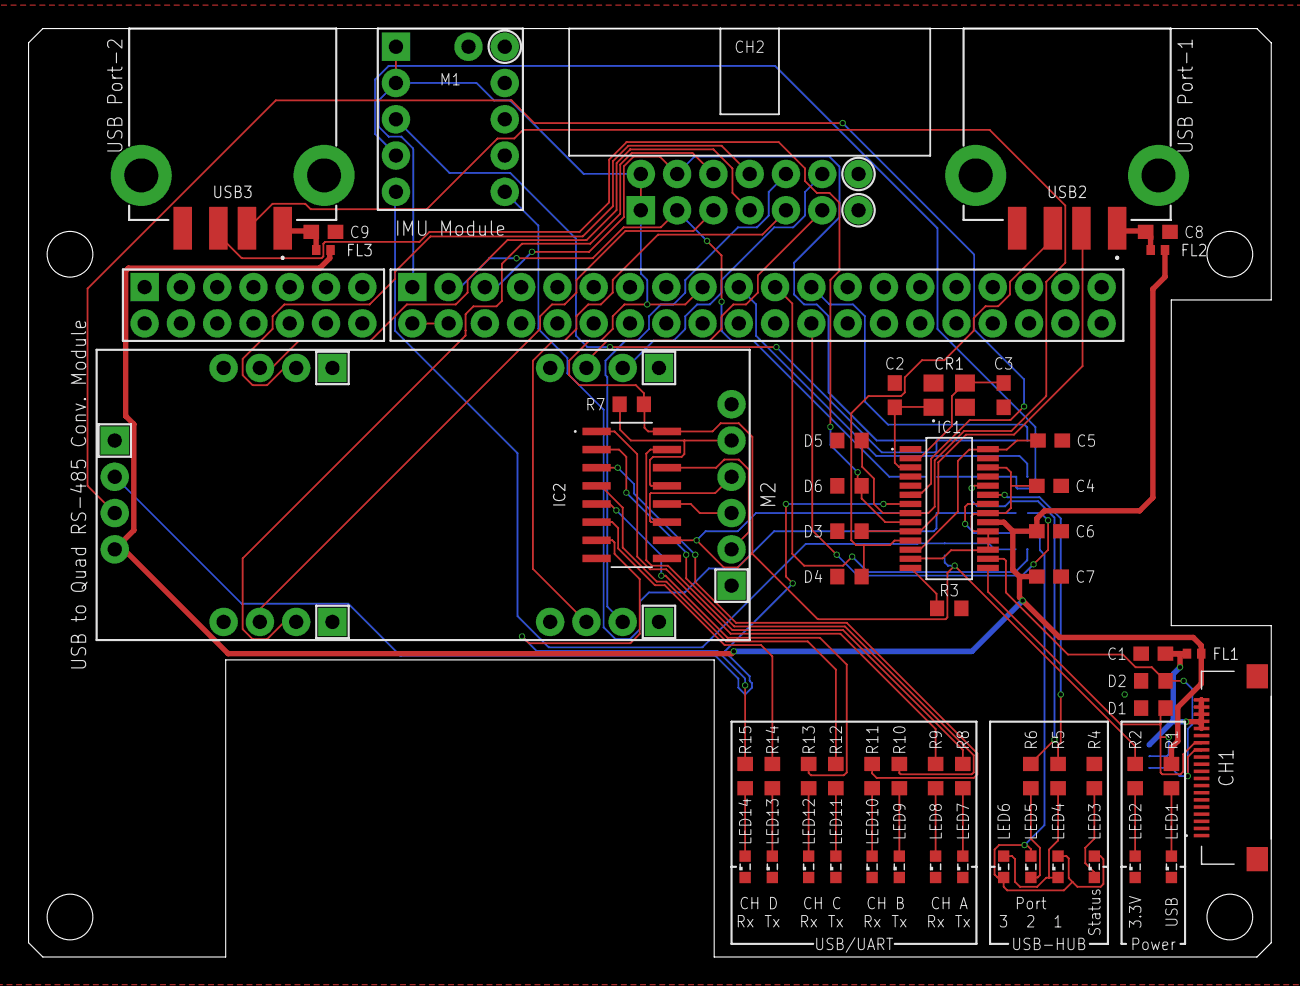
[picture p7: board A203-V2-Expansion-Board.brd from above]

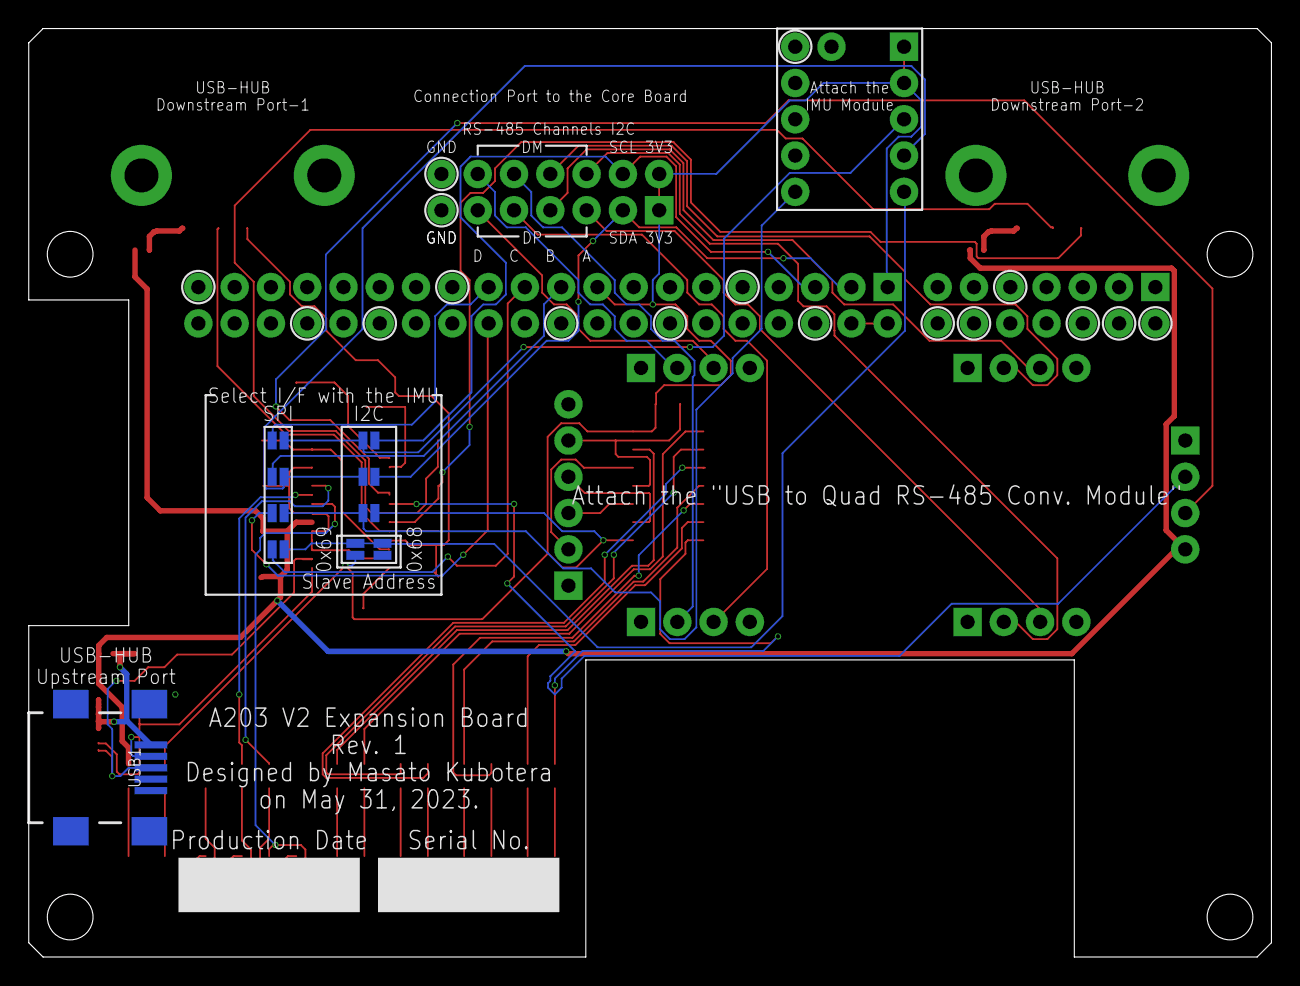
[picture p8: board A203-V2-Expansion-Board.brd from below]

Board: 2 copper layers, 87.0 x 65.0 mm, 67 parts (10 on the bottom side), 66 nets.

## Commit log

2023-05-21 Initial upload
    [A203-V2-Expansion-Board.brd, A203-V2-Expansion-Board.sch, A203-V2-Expansion-Board_top_bom.csv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]
2023-05-23 Fixed silk printing
    [A203-V2-Expansion-Board.brd]
2023-05-23 Update files for PCBA
    [A203-V2-Expansion-Board_top_bom.csv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]
2023-05-23 Update README.md for PCBA
2023-05-23 Update PCB images
2023-05-31 Fixed wiring error on USB DN Port 3
    [A203-V2-Expansion-Board.brd, A203-V2-Expansion-Board.sch]
2023-06-02 Update README.md for pcb order
2023-06-14 Change default display settings
    [A203-V2-Expansion-Board.brd]

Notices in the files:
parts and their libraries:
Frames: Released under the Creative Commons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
